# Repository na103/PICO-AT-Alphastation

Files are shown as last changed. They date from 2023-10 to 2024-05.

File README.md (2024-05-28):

# PICO-AT Power Adapter for DEC Alphastation 200
This adapter allows you to replace the original  DEC Alphastation 200 PSU  with a newer ATX PSU.<br>

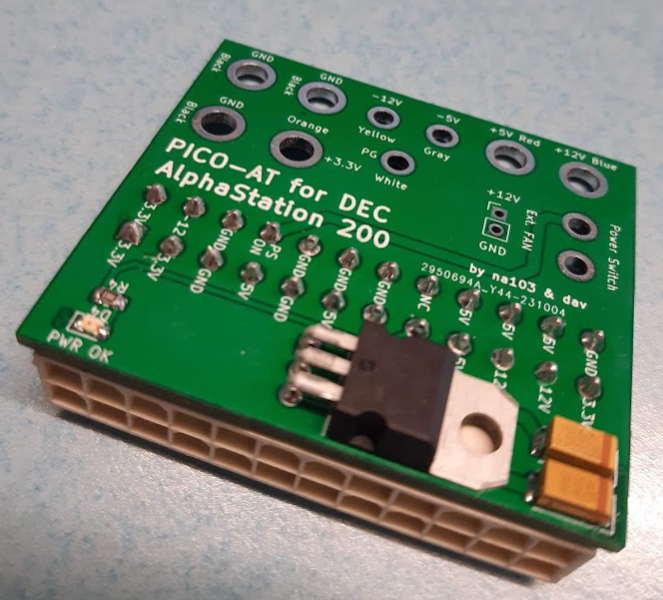
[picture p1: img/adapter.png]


## Bill of materials
| Qt. | Description | Designator | Mouser  Part | 
|:---:|---|---|---|
|1 |Capacitor 2.2uF | C1 |T491C225K035AT |
|1 |Capacitor 1uF | C2 |T491C105K050AT |
|1 |SMD LED | D4 |150080VS75000 |
|1 |ATX 24pin fem conn  | J1 |87427-2402 |
|1 |Resistor 330R | R4 |CR0805-FX-3300ELF |
|1 |Regulator L7905 | U1 |L7905CV |
<br>

## Building notes
The adapter is designed to use the old power cables, power switch and external fan. You must  desolder them from the old one, being careful not to break the terminals.<br>

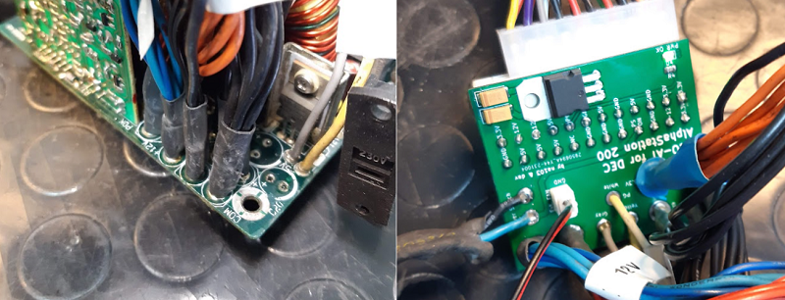
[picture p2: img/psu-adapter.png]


the original psu provides power and control for external 12V fan on the chassis via a temperature sensor<br>
The adapter does not include temperature sensor control, so the fan will always be active.
<br>
Due to the limited space inside the case you need to find a location for the adapter to ensure proper insulation.<br>
maybe if you shortened the cables you could place it inside the ATX PSU

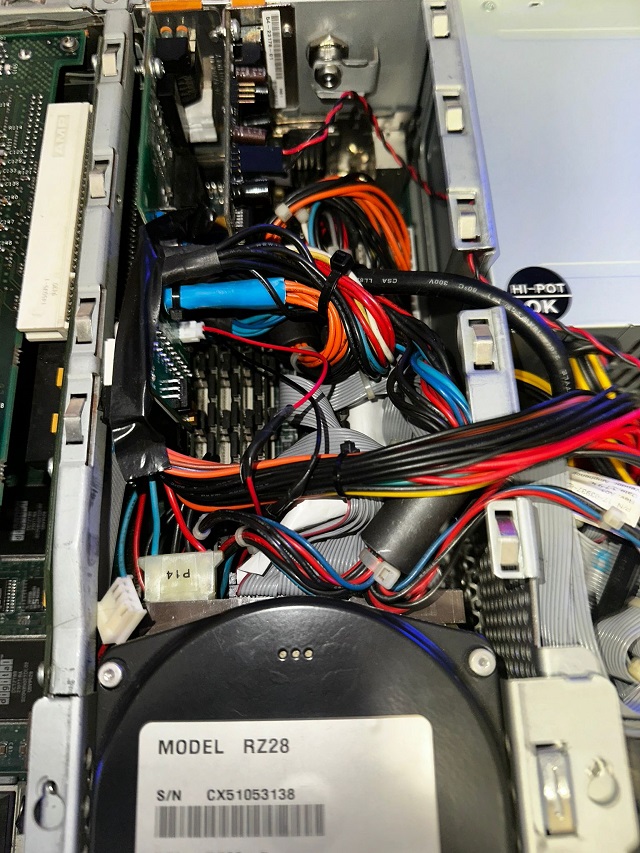
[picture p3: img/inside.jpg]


## Note for ATX PSU replacement
The original ASTEC model AA 19100 power supply has the following characteristics, buy an ATX PSU capable of delivering this power.<br>

| DC output voltage | Current (max) | Cable colour |
|---|---|---|
| +3.3V | 35A | Orange |
| +12V | 4.6A | Blue |
| +5V | 30A | Red |
| -5V | 0.3A | Gray |
| -12V | 0.3A | Yellow |

<br>

## Thanks

Thankyou to all the people who have helped with this project.

- [Wiretrap-retro](https://github.com/wiretap-retro) who created the [PICO-AT](https://github.com/wiretap-retro/PICO-AT-Power-Adapter) that I used as the base design project
- |D|A|V| for testing the adapter in your DEC Alphastation 200

<br>
If you found this my work useful, please consider buying me a cup of coffee if you want:<br>


## License

This work is licensed under a Creative Commons Attribution 4.0 International License. See [https://creativecommons.org/licenses/by/4.0/](https://creativecommons.org/licenses/by/4.0/).

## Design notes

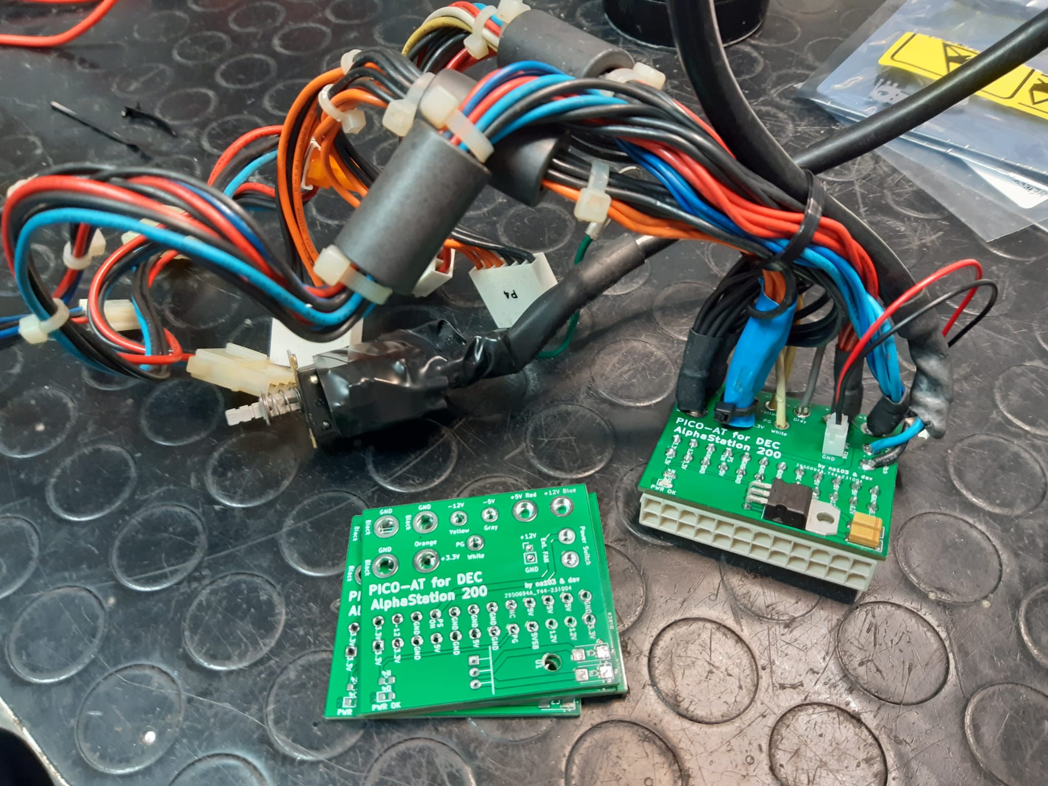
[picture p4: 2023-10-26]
img/withcable.jpg

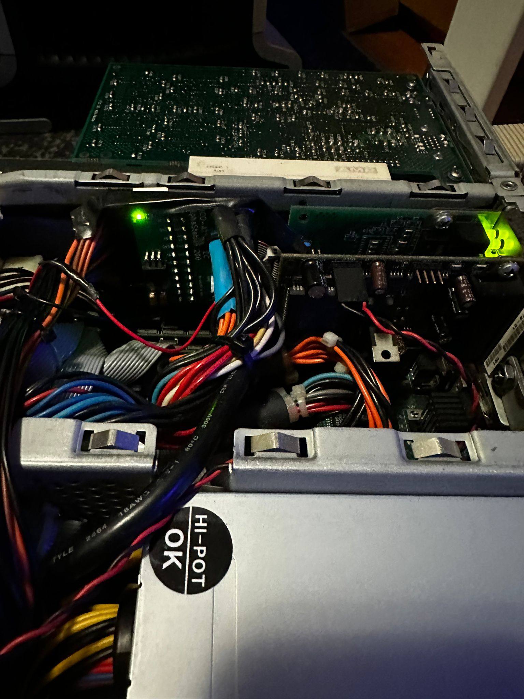
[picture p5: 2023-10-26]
img/inside2.jpg

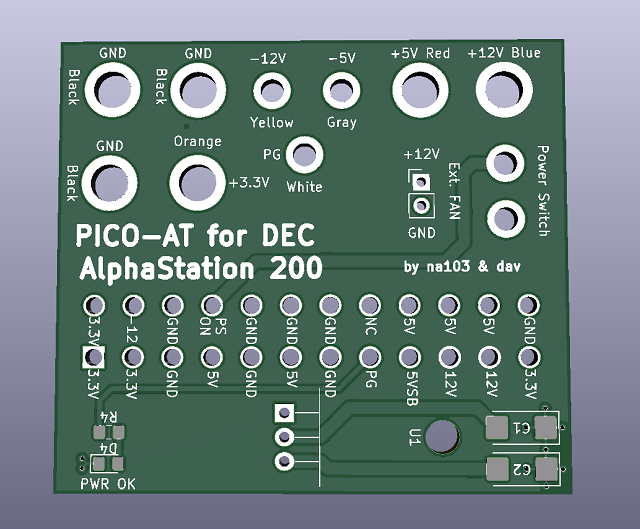
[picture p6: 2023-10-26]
img/pcb.png

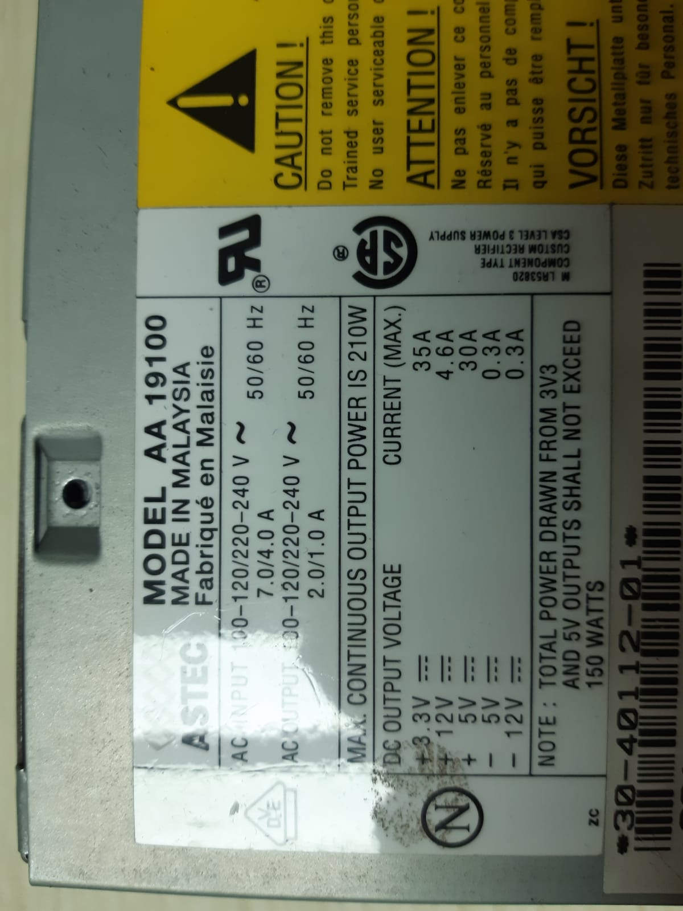
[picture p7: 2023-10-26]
img/OriginalPSU.jpg

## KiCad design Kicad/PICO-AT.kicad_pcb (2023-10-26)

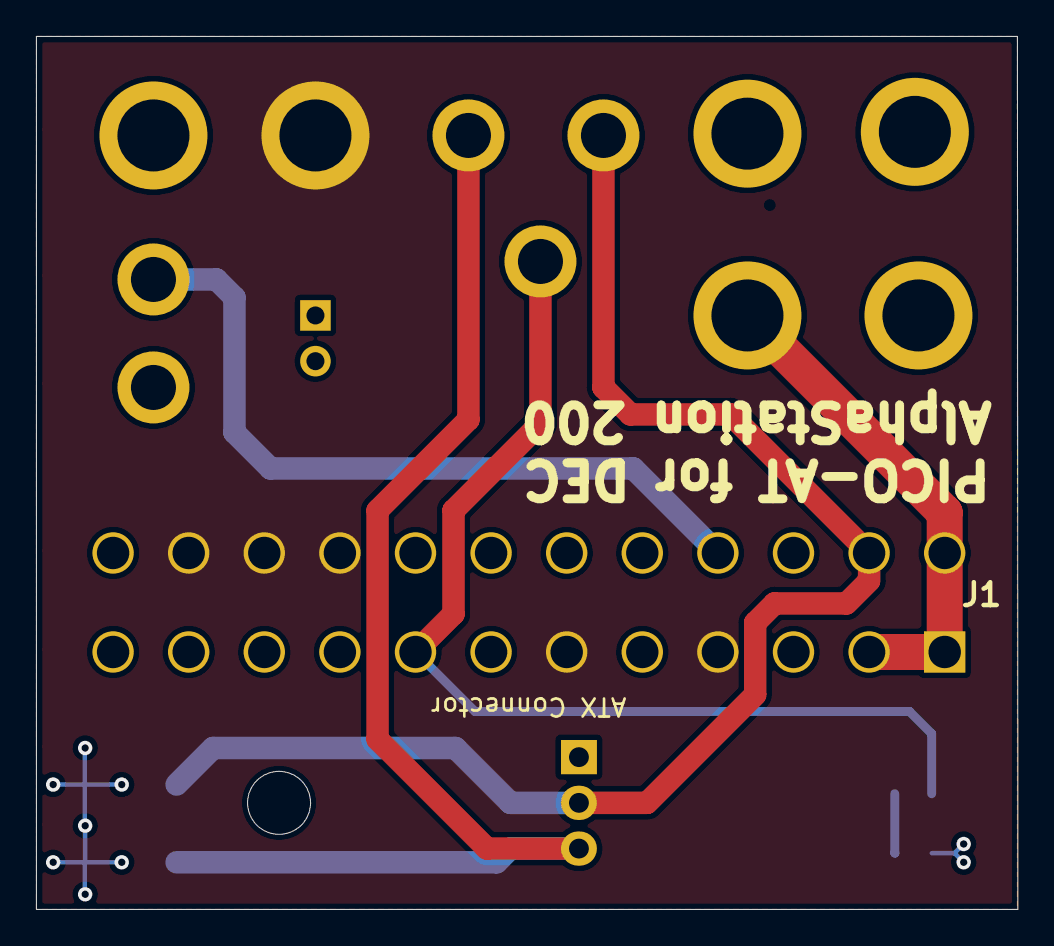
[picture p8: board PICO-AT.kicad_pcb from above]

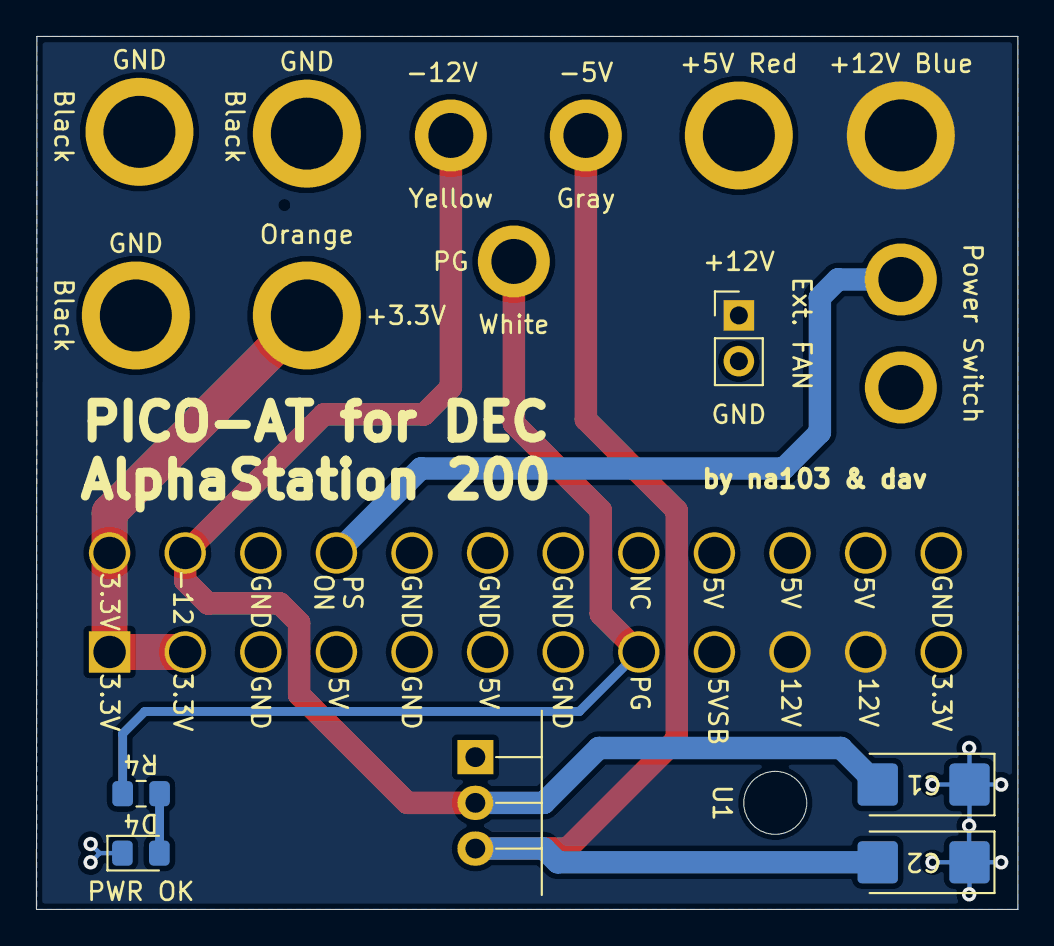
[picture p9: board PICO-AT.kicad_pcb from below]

Board: 4 copper layers, 54.5 x 48.5 mm, 17 parts (6 on the bottom side), 9 nets.

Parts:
+3.3V: Orange; PowerSupply_1x01_P4mm
+5V Red: 5V; PowerSupply_1x01_P4mm
+12V: Ext. FAN; PinHeader_1x02_P2.54mm_Vertical
+12V Blue: 12V; PowerSupply_1x01_P4mm
-5V: Gray; PowerSupply_1x01_P2.5mm
-12V: Yellow; PowerSupply_1x01_P2.5mm
C1: 2.2uF; CP_EIA-6032-28_Kemet-C_Pad2.25x2.35mm_HandSolder
C2: 1uF; CP_EIA-6032-28_Kemet-C_Pad2.25x2.35mm_HandSolder
D4: PWR OK; LED_0805_2012Metric_Pad1.15x1.40mm_HandSolder
GND: Power Switch; PowerSupply_1x02_P2.5mm
GND#2, GND#3, GND#4: Black; PowerSupply_1x01_P4mm
J1: 87427-2402; 87427-24YY_347202
PG: White; PowerSupply_1x01_P2.5mm
R4: 330; R_0805_2012Metric_Pad1.15x1.40mm_HandSolder
U1: L7905; TO-220-3_Horizontal_TabDown

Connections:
/3.3V: +3.3V.1, J1.1, J1.2, J1.13
/5V: +5V Red.1, J1.4, J1.6, J1.21, J1.22, J1.23
/12V: +12V.1, +12V Blue.1, J1.10, J1.11
/-5V: -5V.1, C2.2, U1.3
/-12V: -12V.1, C1.2, J1.14, U1.2
/GND: +12V.2, C1.1, C2.1, D4.1, GND.2, GND#2.1, GND#3.1, GND#4.1, J1.3, J1.5, J1.7, J1.15, J1.17, J1.18, J1.19, J1.24, U1.1
/PG: J1.8, PG.1, R4.1
/PS-ON: GND.1, J1.16
unnamed: D4.2, R4.2
